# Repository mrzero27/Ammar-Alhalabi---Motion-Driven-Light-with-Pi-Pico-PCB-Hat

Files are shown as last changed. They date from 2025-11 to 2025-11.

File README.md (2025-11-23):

# Motion-Driven Water Line – Raspberry Pi Pico (Dual Core)

## 1. What the project does

This project runs on a **Raspberry Pi Pico (RP2040)** and drives a **WS2812B (NeoPixel) LED strip** to display a moving “water line” that reacts to the board’s **tilt**.

- If an **MPU-6050** IMU is connected:
  - The code reads accelerometer + gyroscope data over I²C.
  - It computes the **roll angle** (left/right tilt) and uses it to move a “water blob” along the LED strip.
- If **no sensor is present** or it cannot be detected:
  - The code automatically switches to a **simulated motion mode** that generates a smooth sine-wave roll angle.
  - The program still runs and shows the water animation and ASCII output, even on a bare Pico with only USB.

In all cases:

- A **NeoPixel strip** shows a blue-green “water blob” that sits around the middle and moves left/right with tilt, with soft edges and a small shimmer effect.
- An **ASCII visualization** of the water line is printed to the **Serial Monitor** once per frame, together with live sensor/simulation values.

---

## 2. How to test it (with or without hardware)

### 2.1 With full hardware (Pico + MPU-6050 + WS2812B)

**Connections (default, matching the code):**

**MPU-6050 → Pico (I²C)**

- `VCC` → `3V3(OUT)`
- `GND` → `GND`
- `SDA` → `GP4`
- `SCL` → `GP5`
- `AD0` → `GND` (so the address is `0x68` as used in the code)

**WS2812B LED strip → Pico**

- `DIN` → `GP2`
- `GND` → `GND`
- `VCC` → 5 V or 3.3 V (according to your strip’s requirements; GND must be common with Pico)

**Test procedure:**

1. Connect the Pico to the PC via USB.
2. Open the Arduino sketch and upload it using **Arduino IDE** (board set to **Raspberry Pi Pico**, baud rate 115200).
3. Open **Serial Monitor** at **115200 baud**.
4. On startup, you should see something like:

   ```text
   MPU-6050 detected, using real sensor.

5. Now gently tilt the board left and right:

   * The **roll angle** in the Serial Monitor should change sign and magnitude.
   * The **ASCII water bar** in Serial should move left/right accordingly.
   * The **water blob on the NeoPixel strip** should visually follow the tilt.

This demonstrates the full behavior with real sensor data.

---

### 2.2 Without IMU / without custom PCB (simulation mode)

You can still run and test the project **without any external hardware**:

1. Connect only the **Pico + USB** to your PC (no MPU, no LEDs required).
2. Upload the sketch.
3. Open the **Serial Monitor** at **115200 baud**.

If the IMU is not found, you will see:

```text
MPU-6050 NOT found, falling back to simulated motion.
```

After that:

* The code generates a **simulated roll angle** using a sine wave (no sensor needed).
* Every frame it prints:

  * The simulated roll angle.
  * Fixed accelerometer values (`ax, ay, az`).
  * `src=SIM` to indicate simulation mode.
  * The ASCII water bar, which moves smoothly left/right over time.

If you connect only a **NeoPixel strip** (and no IMU), you will also see the LED water animation driven by the same simulated motion.

This way the project is fully testable both:

* **With real hardware** (IMU + LEDs).
* **With no hardware at all** (bare Pico + Serial Monitor).

---

## 3. How each core is used

The Raspberry Pi Pico has two cores. This project explicitly splits responsibilities:

### Core 0 – Sensor / Simulation and Shared State

Core 0 runs the standard Arduino `setup()` and `loop()` functions.

**Responsibilities:**

* Initialize:

  * Serial at 115200 baud.
  * I²C (using `Wire.setSDA(4)` and `Wire.setSCL(5)`).
  * The MPU-6050 (if present) by pinging its I²C address and waking it from sleep.
  * The NeoPixel strip (pin `GP2`, `LED_COUNT = 24`).
  * Launch **Core 1** using `multicore_launch_core1(core1Task);`.

* In `loop()` (every `SENSOR_INTERVAL_MS = 10 ms`):

  1. Create a local `MotionSample` struct.
  2. If the IMU is present and `readMPU6050(...)` succeeds:

     * Read raw accel/gyro registers.
     * Convert raw values to physical units:

       * Accel in g (`raw / 16384.0`).
       * Gyro in deg/s (`raw / 131.0`).
     * Compute the **roll angle**:
       `rollDeg = atan2(ay, az) * 180 / PI;`
     * Mark `sensorOk = true`.
  3. Otherwise:

     * Call `generateSimulatedMotion(...)` to compute a **sine-wave roll angle** (±30°) with fixed accel values.
     * Mark `sensorOk = false` (simulation mode).
  4. Store the resulting `MotionSample` into the global `g_motion` struct, which is shared with Core 1.

**Summary:** Core 0 is responsible for **“what is the current motion?”**, using either real IMU data or a simulated pattern, and publishes that as a shared state.

---

### Core 1 – LED Rendering and ASCII Output

Core 1 runs the `core1Task()` function in parallel.

**Responsibilities (every `FRAME_INTERVAL_MS = 50 ms`):**

1. Copy the shared `g_motion` into a local variable inside a `noInterrupts()/interrupts()` block to avoid partial updates.
2. Take `rollDeg` from the motion sample and map it to a normalized tilt value in **[-1, 1]** using `mapRollToTilt()`:

   * Clamp roll to ±45°.
   * Divide by 45° to get −1…+1.
3. Call `updateLeds(tiltNorm)`:

   * Compute a **center index** along the LED strip based on the tilt.
   * Reflect the center when it would move off the ends (simple “bounce” effect).
   * Apply a **soft radius** around the center to create a blob (triangular falloff).
   * Add a small **shimmer** (time-based modulation) to make the water look alive.
   * Set NeoPixel colors to a blue-ish water tone and call `strip.show()`.
4. Call `buildAsciiWaterLine(tiltNorm)`:

   * Use the same conceptual center and radius over a string of length `LED_COUNT` (or 20 as fallback).
   * Write:

     * `O` at the center.
     * `~` and `-` around the center within the radius.
     * `_` elsewhere.
   * Returns a single-line ASCII representation of the water.
5. Print a single line to Serial combining:

   * Roll angle.
   * `ax, ay, az`.
   * The source (`MPU` or `SIM`).
   * The ASCII water bar.

**Summary:** Core 1 is responsible for **visualization**, both on the **LED strip** and in the **Serial Monitor**, using the motion state produced by Core 0.

---

## 4. Sample Serial Monitor output

### Example with a detected MPU-6050 (real sensor data)

```text
MPU-6050 detected, using real sensor.
roll=-7.5 deg | ax=0.01g ay=-0.13g az=0.98g | src=MPU | water: ____---~~O~~---_________
roll= 0.2 deg | ax=0.00g ay= 0.00g az=1.00g | src=MPU | water: ______---~~O~~---_______
roll=18.9 deg | ax=0.03g ay= 0.32g az=0.94g | src=MPU | water: _________---~~O~~---____
```

### Example in simulation mode (no IMU / not detected)

```text
MPU-6050 NOT found, falling back to simulated motion.
roll=  9.4 deg | ax=0.00g ay=0.00g az=1.00g | src=SIM | water: _______---~~O~~---______
roll= 28.1 deg | ax=0.00g ay=0.00g az=1.00g | src=SIM | water: __________---~~O~~--___
roll= -5.6 deg | ax=0.00g ay=0.00g az=1.00g | src=SIM | water: ____---~~O~~---_________
```

Field meanings:

* `roll`: roll angle in degrees (negative = tilt one way, positive = tilt the other).
* `ax, ay, az`: acceleration components in g.
* `src`:

  * `MPU` = real MPU-6050 readings.
  * `SIM` = internal simulated motion.
* `water`: ASCII representation of the LED strip:

  * `O` = center of the blob.
  * `~` and `-` = body and edges of the water.
  * `_` = empty space.

---

## 5. PCB Layout & 3D Views

### 5.1 Top 3D view – Pico plugged into the hat

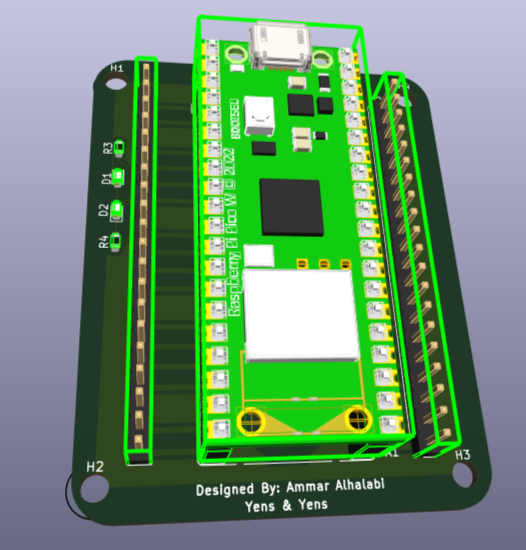
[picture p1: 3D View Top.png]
Top 3D view – Pico hat


This render shows the **Raspberry Pi Pico** plugged into the custom hat.
You can see the **stacking headers** on both sides, the LEDs along the Pico edge, and the overall mechanical outline with four mounting holes.
The silkscreen at the bottom credits the designer and clearly labels the board.

---

### 5.2 Bottom 3D view – IMU and passives

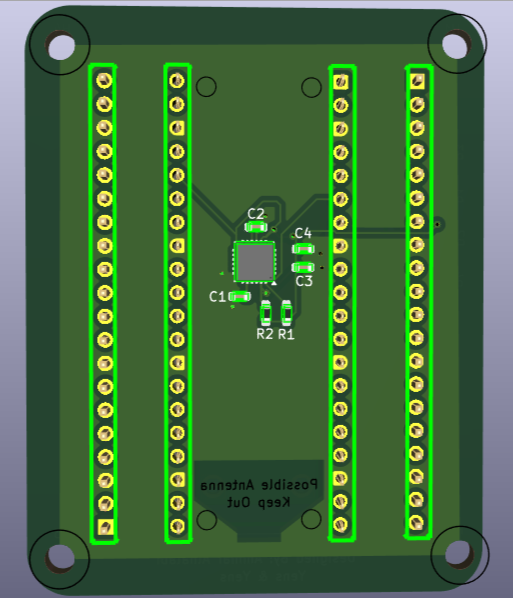
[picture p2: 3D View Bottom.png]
Bottom 3D view – IMU section


This is the **bottom side** of the PCB.
In the middle you can see the **MPU-6050** IMU and its surrounding capacitors and resistors (decoupling and pull-ups).
The four long female headers give access to all Pico GPIO pins while keeping the IMU wiring short and symmetric.

---

### 5.3 Top copper/layout view – routing and keep-out

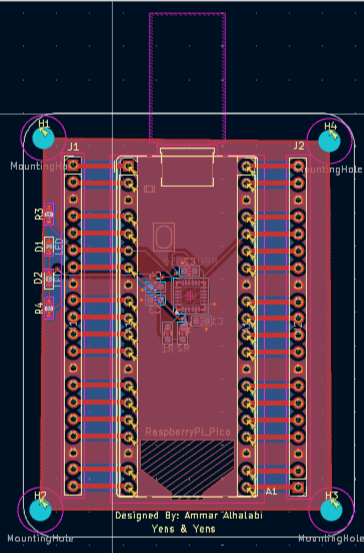
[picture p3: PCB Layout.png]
2D layout – routing


This 2D layout view shows the **copper pours, traces and keep-out area** under the Pico’s antenna.
You can see how the I²C lines from the Pico are routed cleanly to the IMU, how the ground pour ties everything together, and how the four mounting holes define the mechanical footprint.

---

### 5.4 Schematic – Pico, IMU and indicators

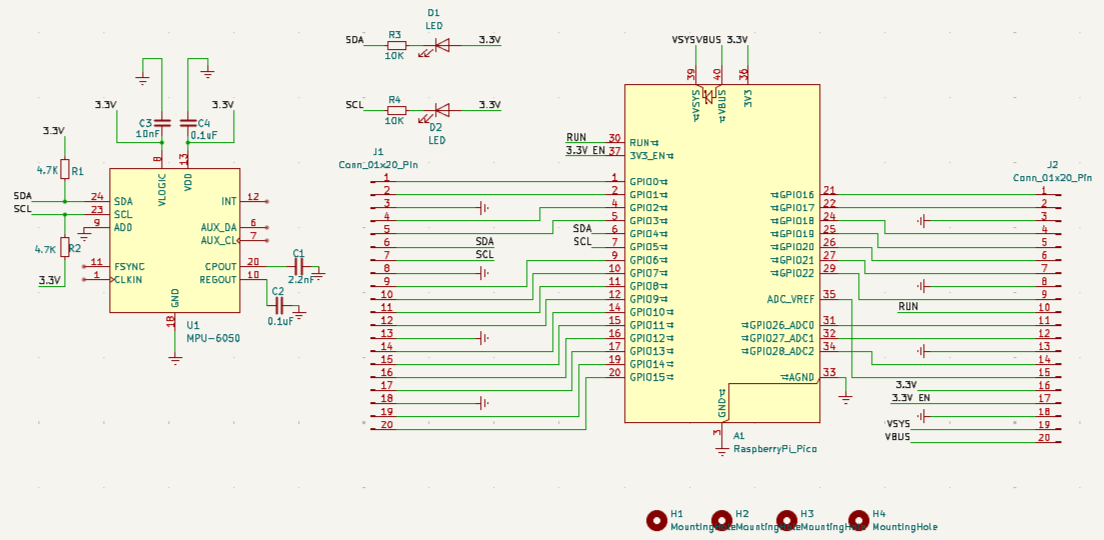
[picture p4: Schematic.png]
Schematic – Pico + MPU-6050


The schematic shows the overall design:

* On the left, the **MPU-6050** with its power decoupling capacitors, I²C pull-up resistors and address pin configuration.
* At the top, **SDA/SCL indicator LEDs** with series resistors so you can visually see I²C activity.
* On the right, the **Raspberry Pi Pico** with both 20-pin headers broken out and power rails (3V3, VSYS/VBUS, GND) distributed to the connectors.

These four images together document how the PCB implements the firmware concept in hardware: Pico in the center, IMU close and quiet, and all GPIOs still available through the side headers.

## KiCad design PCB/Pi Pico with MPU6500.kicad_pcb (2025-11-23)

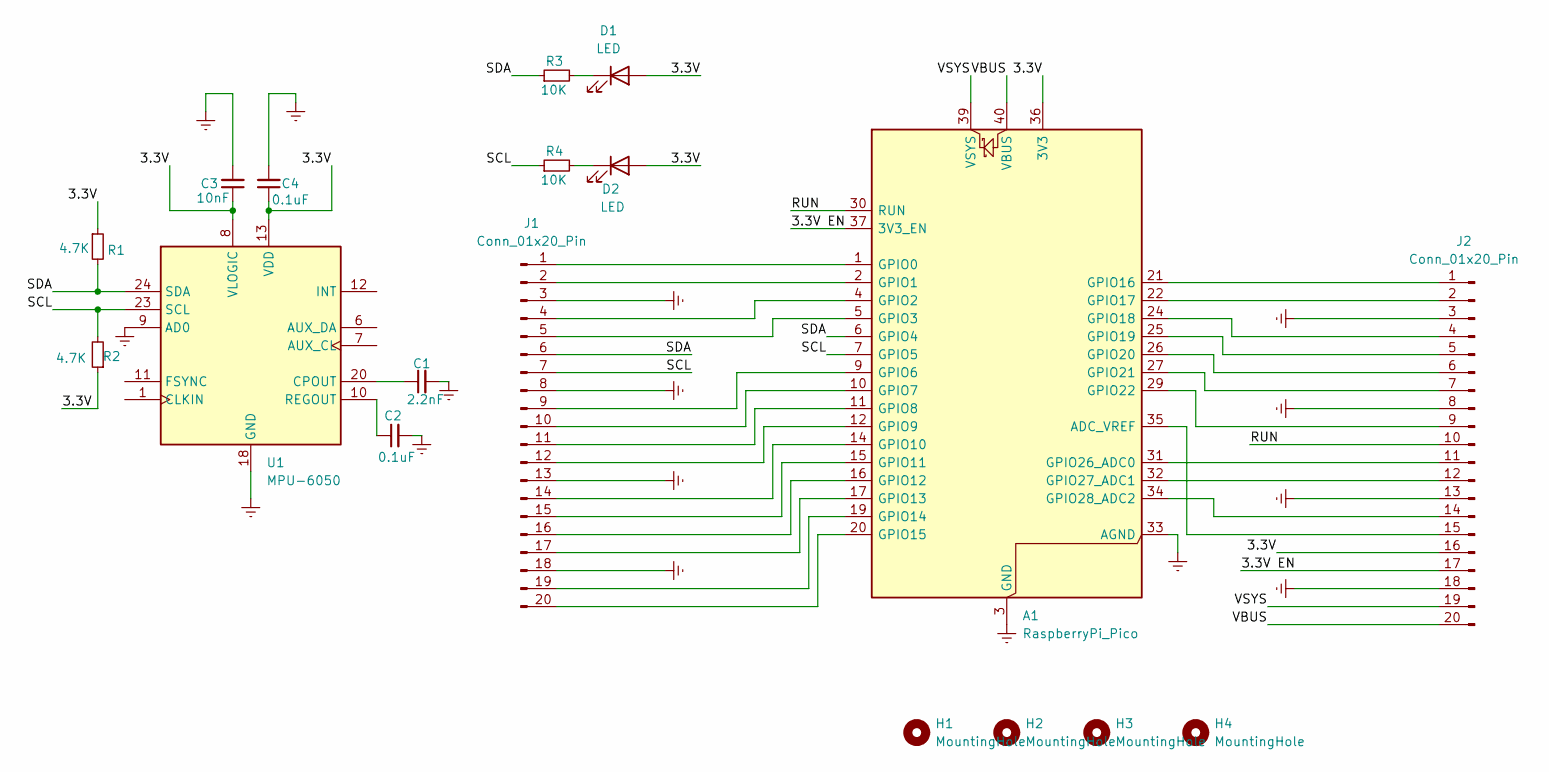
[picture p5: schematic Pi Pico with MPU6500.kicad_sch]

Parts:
A1: RaspberryPi_Pico; RaspberryPi_Pico_Common_THT
C1: 2.2nF; C_0603_1608Metric
C2, C4: 0.1uF; C_0603_1608Metric
C3: 10nF; C_0603_1608Metric
D1, D2: LED; LED_0603_1608Metric
H1, H2, H3, H4: MountingHole; MountingHole_3.2mm_M3
J1, J2: Conn_01x20_Pin; PinHeader_1x20_P2.54mm_Vertical
R1, R2: 4.7K; R_0603_1608Metric_Pad0.98x0.95mm_HandSolder
R3, R4: 10K; R_0603_1608Metric_Pad0.98x0.95mm_HandSolder
U1: MPU-6050; InvenSense_QFN-24_4x4mm_P0.5mm

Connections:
/3.3V: A1.36 (3V3), C3.1, C4.1, D1.2 (A), D2.2 (A), J2.16, R1.1, R2.1, U1.8 (VLOGIC), U1.13 (VDD)
/3.3V EN: A1.37 (3V3_EN), J2.17
/RUN: A1.30 (RUN), J2.10
/SCL: A1.7 (GPIO5), J1.7, R2.2, R4.1, U1.23 (SCL)
/SDA: A1.6 (GPIO4), J1.6, R1.2, R3.1, U1.24 (SDA)
/VBUS: A1.40 (VBUS), J2.20
/VSYS: A1.39 (VSYS), J2.19
Earth: A1.3 (GND), A1.8 (GND), A1.13 (GND), A1.18 (GND), A1.23 (GND), A1.28 (GND), A1.33 (AGND), A1.38 (GND), C1.2, C2.2, C3.2, C4.2, J1.3, J1.8, J1.13, J1.18, J2.3, J2.8, J2.13, J2.18, U1.9 (AD0), U1.18 (GND)
unnamed: A1.35 (ADC_VREF), J2.15
unnamed: A1.1 (GPIO0), J1.1
unnamed: A1.2 (GPIO1), J1.2
unnamed: A1.4 (GPIO2), J1.4
unnamed: A1.5 (GPIO3), J1.5
unnamed: A1.9 (GPIO6), J1.9
unnamed: A1.10 (GPIO7), J1.10
unnamed: A1.11 (GPIO8), J1.11
unnamed: A1.12 (GPIO9), J1.12
unnamed: A1.14 (GPIO10), J1.14
unnamed: A1.15 (GPIO11), J1.15
unnamed: A1.16 (GPIO12), J1.16
unnamed: A1.17 (GPIO13), J1.17
unnamed: A1.19 (GPIO14), J1.19
unnamed: A1.20 (GPIO15), J1.20
unnamed: A1.21 (GPIO16), J2.1
unnamed: A1.22 (GPIO17), J2.2
unnamed: A1.24 (GPIO18), J2.4
unnamed: A1.25 (GPIO19), J2.5
unnamed: A1.26 (GPIO20), J2.6
unnamed: A1.27 (GPIO21), J2.7
unnamed: A1.29 (GPIO22), J2.9
unnamed: A1.31 (GPIO26_ADC0), J2.11
unnamed: A1.32 (GPIO27_ADC1), J2.12
unnamed: A1.34 (GPIO28_ADC2), J2.14
unnamed: D1.1 (K), R3.2
unnamed: D2.1 (K), R4.2
unnamed: C1.1, U1.20 (CPOUT)
unnamed: C2.1, U1.10 (REGOUT)

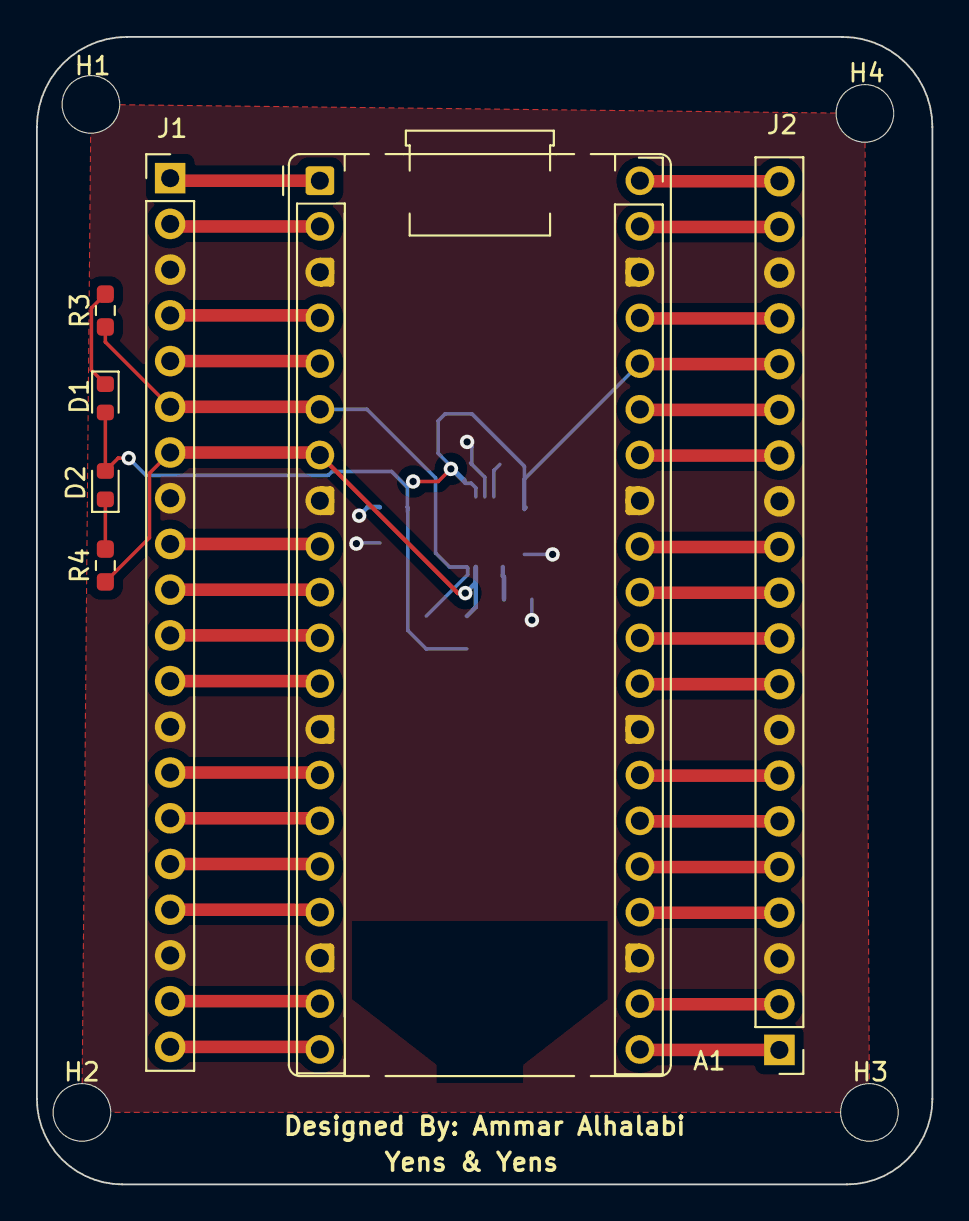
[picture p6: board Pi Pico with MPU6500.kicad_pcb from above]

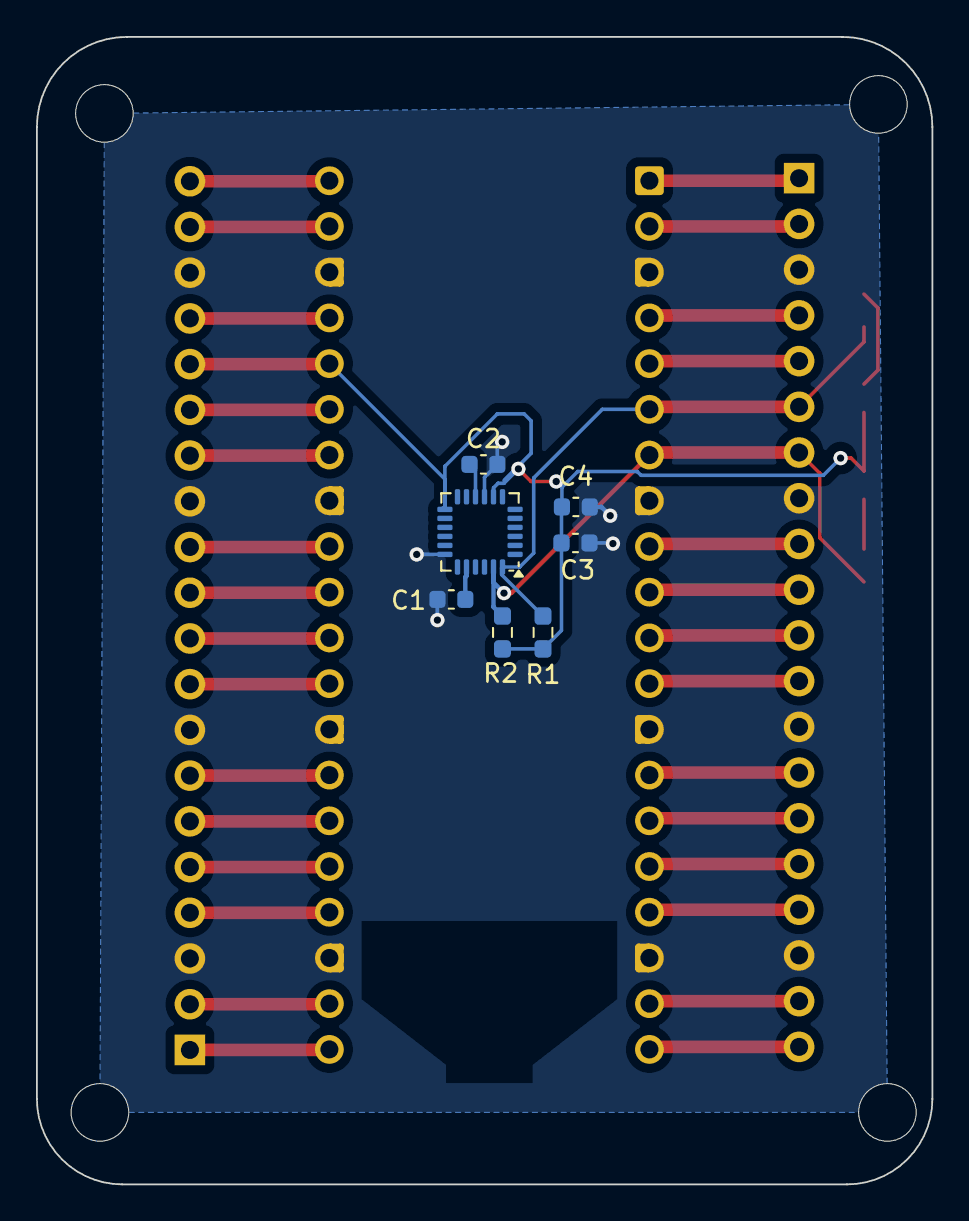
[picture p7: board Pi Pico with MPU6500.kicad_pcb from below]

Board: 2 copper layers, 49.8 x 63.8 mm, 18 parts (7 on the bottom side), 37 nets.

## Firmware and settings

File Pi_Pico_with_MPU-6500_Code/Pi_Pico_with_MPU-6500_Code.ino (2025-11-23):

#include <Arduino.h>
#include <Wire.h>
#include <Adafruit_NeoPixel.h>
#include "pico/multicore.h"

// ---------------------- USER CONFIG ----------------------

// WS2812B LED strip settings
#define LED_PIN     2          // GPIO pin for data line to WS2812B
#define LED_COUNT   24         // Number of LEDs in the strip

// I2C / MPU6050
#define I2C_SDA_PIN  4         // Change to your hat wiring if needed
#define I2C_SCL_PIN  5
#define MPU_ADDR     0x68

// Update rates
const uint16_t SENSOR_INTERVAL_MS = 10;   // Core0: sensor / simulation update period
const uint16_t FRAME_INTERVAL_MS  = 50;   // Core1: LED + ASCII frame rate (~20 FPS)

// ---------------------- GLOBAL STATE ----------------------

struct MotionSample {
  float ax, ay, az;    // acceleration in g
  float gx, gy, gz;    // gyro in deg/s (not heavily used here)
  float rollDeg;       // left/right tilt angle in degrees (for water)
  bool  sensorOk;      // true if data from real sensor, false if simulated
};

// FIX: not volatile, so we can copy-assign without compiler complaining
MotionSample g_motion = {0, 0, 1, 0, 0, 0, 0, false};
volatile bool g_mpuPresent = false;

// LED strip object (Core1 will use it)
Adafruit_NeoPixel strip(LED_COUNT, LED_PIN, NEO_GRB + NEO_KHZ800);

// ---------------------- MPU6050 LOW-LEVEL ----------------------

bool mpuWriteRegister(uint8_t reg, uint8_t value) {
  Wire.beginTransmission(MPU_ADDR);
  Wire.write(reg);
  Wire.write(value);
  return (Wire.endTransmission() == 0);
}

bool mpuReadBytes(uint8_t startReg, uint8_t *buffer, uint8_t length) {
  Wire.beginTransmission(MPU_ADDR);
  Wire.write(startReg);
  if (Wire.endTransmission(false) != 0) {
    return false;
  }
  uint8_t readCount = Wire.requestFrom(MPU_ADDR, length);
  if (readCount != length) {
    return false;
  }
  for (uint8_t i = 0; i < length; i++) {
    buffer[i] = Wire.read();
  }
  return true;
}

bool initMPU6050() {
  // Simple presence check
  Wire.beginTransmission(MPU_ADDR);
  if (Wire.endTransmission() != 0) {
    return false;
  }

  // Wake up the MPU6050 (clear sleep bit in PWR_MGMT_1)
  if (!mpuWriteRegister(0x6B, 0x00)) {
    return false;
  }

  // Optional: set accelerometer ±2g, gyro ±250 dps (default)
  // ACCEL_CONFIG (0x1C), GYRO_CONFIG (0x1B) if you want to be explicit.

  return true;
}

// Reads accel/gyro, computes roll angle (tilt left/right)
bool readMPU6050(MotionSample &out) {
  uint8_t data[14];
  if (!mpuReadBytes(0x3B, data, 14)) {
    return false;
  }

  int16_t rawAx = (data[0] << 8) | data[1];
  int16_t rawAy = (data[2] << 8) | data[3];
  int16_t rawAz = (data[4] << 8) | data[5];
  // int16_t rawTemp = (data[6] << 8) | data[7]; // not used
  int16_t rawGx = (data[8] << 8) | data[9];
  int16_t rawGy = (data[10] << 8) | data[11];
  int16_t rawGz = (data[12] << 8) | data[13];

  // Convert to physical units
  const float ACCEL_SCALE = 16384.0f; // LSB/g for ±2g
  const float GYRO_SCALE  = 131.0f;   // LSB/(deg/s) for ±250 dps

  out.ax = (float)rawAx / ACCEL_SCALE;
  out.ay = (float)rawAy / ACCEL_SCALE;
  out.az = (float)rawAz / ACCEL_SCALE;

  out.gx = (float)rawGx / GYRO_SCALE;
  out.gy = (float)rawGy / GYRO_SCALE;
  out.gz = (float)rawGz / GYRO_SCALE;

  // Compute roll angle (rotation around X axis, left/right tilt)
  // roll = atan2(Ay, Az)
  float rollRad = atan2(out.ay, out.az);
  out.rollDeg = rollRad * 180.0f / PI;

  out.sensorOk = true;
  return true;
}

// ---------------------- SIMULATED MOTION (NO SENSOR) ----------------------

void generateSimulatedMotion(MotionSample &out) {
  // Simple smooth "rocking" motion using sine wave
  float t = millis() / 1000.0f;
  out.ax = 0.0f;
  out.ay = 0.0f;
  out.az = 1.0f;

  out.gx = 0.0f;
  out.gy = 0.0f;
  out.gz = 0.0f;

  out.rollDeg = 30.0f * sinf(t * 0.8f); // ±30°
  out.sensorOk = false;
}

// ---------------------- WATER RENDERING (CORE 1) ----------------------

// Map roll angle (deg) to normalized tilt [-1, 1]
float mapRollToTilt(float rollDeg) {
  // Clamp roll to ±45°
  float clamped = constrain(rollDeg, -45.0f, 45.0f);
  return clamped / 45.0f; // -1 at -45°, +1 at +45°
}

// Update physical LEDs to show water "blob"
void updateLeds(float tiltNorm) {
  if (LED_COUNT <= 0) return;

  int mid = LED_COUNT / 2;
  // Shift center with tilt
  float maxShift = (LED_COUNT / 2) - 1;
  float centerF = mid + tiltNorm * maxShift;

  // Simple edge "bounce" illusion: if center goes beyond edges, reflect
  if (centerF < 0) {
    centerF = -centerF;  // reflect at left
  } else if (centerF > LED_COUNT - 1) {
    centerF = 2 * (LED_COUNT - 1) - centerF; // reflect at right
  }

  // Soft radius of water
  const float RADIUS = LED_COUNT * 0.25f; // 1/4 of strip

  for (int i = 0; i < LED_COUNT; i++) {
    float dist = fabsf(i - centerF);
    float base = 0.0f;

    if (dist < RADIUS) {
      // Simple triangular falloff
      base = 1.0f - (dist / RADIUS);
    } else {
      base = 0.0f;
    }

    // Add a tiny shimmer by modulating with time
    float t = millis() / 1000.0f;
    float shimmer = 0.15f * (0.5f + 0.5f * sinf(t * 8.0f + i * 0.6f));

    float brightness = constrain(base + shimmer, 0.0f, 1.0f);

    // Water: blue-ish, with a hint of green
    uint8_t r = 0;
    uint8_t g = (uint8_t)(brightness * 50.0f);
    uint8_t b = (uint8_t)(brightness * 180.0f);

    strip.setPixelColor(i, strip.Color(r, g, b));
  }

  strip.show();
}

// Build ASCII representation of water for Serial Monitor
String buildAsciiWaterLine(float tiltNorm) {
  int length = LED_COUNT > 0 ? LED_COUNT : 20; // fallback to 20 chars if LED_COUNT invalid
  String s;
  s.reserve(length);

  int mid = length / 2;
  float maxShift = (length / 2) - 1;
  float centerF = mid + tiltNorm * maxShift;

  // Same reflection trick as LED
  if (centerF < 0) {
    centerF = -centerF;
  } else if (centerF > length - 1) {
    centerF = 2 * (length - 1) - centerF;
  }

  const float RADIUS = length * 0.25f;

  for (int i = 0; i < length; i++) {
    float dist = fabsf(i - centerF);
    if (dist < 0.5f) {
      // Center of the water blob
      s += 'O';         // strong center
    } else if (dist < RADIUS * 0.4f) {
      s += '~';         // wavy water core
    } else if (dist < RADIUS) {
      s += '-';         // weaker rim
    } else {
      s += '_';         // empty
    }
  }

  return s;
}

// ---------------------- CORE 1 TASK ----------------------

void core1Task() {
  // Small delay to let Core0 finish setup
  delay(1500);

  while (true) {
    // Copy shared motion (single struct copy; fine for this use case)
    MotionSample local;
    noInterrupts();
    local = g_motion;
    interrupts();

    float tiltNorm = mapRollToTilt(local.rollDeg);

    // Update LEDs
    updateLeds(tiltNorm);

    // Build ASCII water line
    String water = buildAsciiWaterLine(tiltNorm);

    // Print one line per frame: sensor values + ASCII
    Serial.print("roll=");
    Serial.print(local.rollDeg, 1);
    Serial.print(" deg");

    Serial.print(" | ax=");
    Serial.print(local.ax, 2);
    Serial.print("g ay=");
    Serial.print(local.ay, 2);
    Serial.print("g az=");
    Serial.print(local.az, 2);
    Serial.print("g");

    Serial.print(" | src=");
    Serial.print(local.sensorOk ? "MPU" : "SIM");

    Serial.print(" | water: ");
    Serial.println(water);   // ONE line per frame, no flicker

    delay(FRAME_INTERVAL_MS);
  }
}

// ---------------------- ARDUINO CORE 0 (setup/loop) ----------------------

void setup() {
  Serial.begin(115200);
  delay(1000);

  // I2C setup
  Wire.setSDA(I2C_SDA_PIN);
  Wire.setSCL(I2C_SCL_PIN);
  Wire.begin();

  // Try to init MPU6050
  g_mpuPresent = initMPU6050();

  if (g_mpuPresent) {
    Serial.println("MPU-6050 detected, using real sensor.");
  } else {
    Serial.println("MPU-6050 NOT found, falling back to simulated motion.");
  }

  // LED strip init
  strip.begin();
  strip.clear();
  strip.show();

  // Start second core
  multicore_launch_core1(core1Task);
}

void loop() {
  static uint32_t lastSampleMs = 0;
  uint32_t now = millis();

  if (now - lastSampleMs >= SENSOR_INTERVAL_MS) {
    lastSampleMs = now;

    MotionSample sample;

    if (g_mpuPresent && readMPU6050(sample)) {
      // OK, real sensor data
      g_motion = sample;
    } else {
      // Either no sensor at all or read failed -> simulate
      generateSimulatedMotion(sample);
      g_motion = sample;
    }
  }

  // Core0 doesn't need to do anything else
}
